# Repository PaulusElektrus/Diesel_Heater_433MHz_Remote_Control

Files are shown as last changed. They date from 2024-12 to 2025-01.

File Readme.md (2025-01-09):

# Diesel Heater 433 MHz Remote Control

This project is based on [ChilliChump`s Project](https://github.com/ChilliChump/Diesel-Heater-433mhz-Remote-Control). 

Its goal is to control a diesel heater to be a frost guard.

The states are as follows:

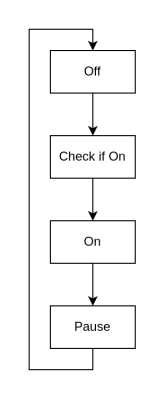
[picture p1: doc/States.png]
States


It is done with an Arduino, DHT22 (temperature sensor) and a 433MHz Transmitter.
We sniff and use the protocoll of the original remote control of the heater.

I use the very nice [Arduino Extension for VSCode](https://github.com/microsoft/vscode-arduino), sadly it is deprecated...

## Projectplan / To-do:

- [X] Basic 433MHz Send & Receive Test
- [X] Sniff Remote Control Codes
- [X] DHT22 integration & test
- [X] Programming
- [X] Design Circuit Board 
- [X] Build Circuit Board
- [X] Final Tests
- [X] Integration

## Basic 433Mhz Send & Receive Test

You can install the [rc-switch library](https://docs.arduino.cc/libraries/rc-switch/) in the library manager of the [Arduino IDE](https://www.arduino.cc/en/software). 

Then the ReceiveDemo_Advanced and the SendDemo can be found under "Examples" in the IDE. Just load it on two separate Microcontrollers and open the serial monitor on the receiving one with baudrate 9600. You should now see the received data which was sent from the transmitting Microcontroller.

## Sniffed Remote Control Codes

I used [the receive demo advanced example script](https://github.com/sui77/rc-switch/tree/master/examples/ReceiveDemo_Advanced) to sniff the remote control codes:

### Chinese Diesel Heater Protocol

#### On:
Decimal: 2794262960 (32Bit) 

Binary: 10100110100011010001000110110000 

Tri-State: not applicable 

PulseLength: 257 microseconds 

Protocol: 1

#### Off:
Decimal: 2794259720 (32Bit) 

Binary: 10100110100011010000010100001000 

Tri-State: not applicable 

PulseLength: 257 microseconds 

Protocol: 1

#### +:
Decimal: 2794260720 (32Bit) 

Binary: 10100110100011010000100011110000 

Tri-State: not applicable 

PulseLength: 257 microseconds 

Protocol: 1

#### -:
Decimal: 2794259080 (32Bit) 

Binary: 10100110100011010000001010001000 

Tri-State: not applicable 

PulseLength: 256 microseconds 

Protocol: 1

## DHT22 Test

The DHT22 can be tested with the [Unified Sensor Example](https://github.com/adafruit/DHT-sensor-library/tree/master/examples/DHT_Unified_Sensor). 

You can install the [DHT sensor library](https://docs.arduino.cc/libraries/dht-sensor-library/) in the library manager. Then the DHT_Unified_Sensor example can be found under "Examples" in the IDE. Just load in on the Microcontroller and open the serial monitor with baudrate 9600. You should see actual temperature and humidity in the serial monitor.

## Schematic

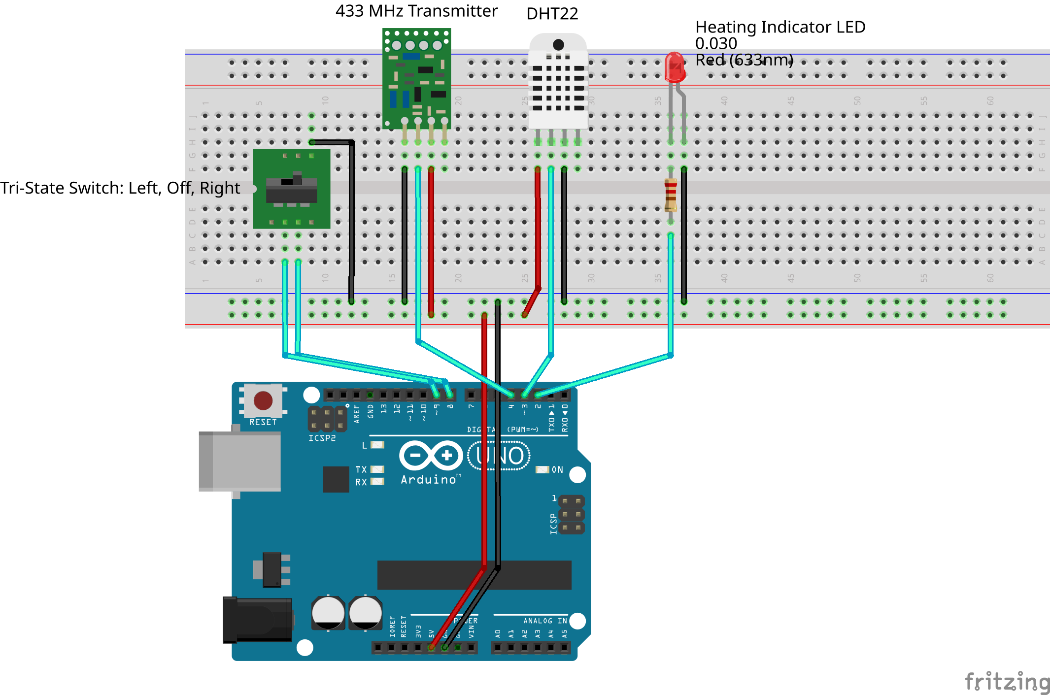
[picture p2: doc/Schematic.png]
Schematic


## Built Project

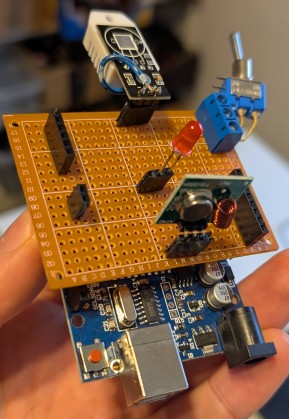
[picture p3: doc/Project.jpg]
Project


## Serial Interface

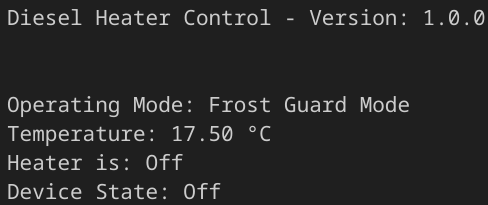
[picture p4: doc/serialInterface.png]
serialInterface


### Admin Mode

Connect to the Microcontroller via serial Inferface:

- Baudrate: 115200
- No line endings!

Then enter "Admin" and send as plain UTF-8 characters.

You can now do the following:

1) Switch On
2) Switch Off
3) Set Debug Temperature
4) Disable Debug
5) Trigger Error
6) Print actual Settings
7) Reset State to Off
8) Trigger serial Report

Every other key ends Admin Mode. You can reenter it by typing "Admin" again.

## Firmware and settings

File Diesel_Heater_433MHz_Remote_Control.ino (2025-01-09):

/* Diesel Heater 433 MHz Remote Control */

#define VERSION             "2.0.1 - PaulusElektrus"             

/* Temperature Sensor Library */
#include <DHT.h>
/* 433 MHz Library */
#include <RCSwitch.h>

/* Pin Assignment */
#define LED_PIN             2
#define DHT_PIN             3
#define TRANSMITTER_PIN     4
#define SWITCH_FROST_GUARD  8
#define SWITCH_AT_HOME      9

/* User Settings */
#define FROST_ON_TEMP               3.0     /* °C */
#define FROST_OFF_TEMP              10.0    /* °C */
#define FROST_PAUSE_TIME            30      /* Minutes */
#define FROST_SWITCH_ON_TIME        10      /* Minutes */
#define FROST_SWITCH_ON_DELTA_T     3.0     /* °C */
#define FROST_MAX_ON_TIME           30      /* Minutes */
#define FROST_RETRY_COUNT           1       /* times */
#define FROST_TIMES_MINUS_KNOB      5       /* times */

#define HOME_ON_TEMP                15.0    /* °C */
#define HOME_OFF_TEMP               25.0    /* °C */
#define HOME_PAUSE_TIME             30      /* Minutes */
#define HOME_SWITCH_ON_TIME         10      /* Minutes */
#define HOME_SWITCH_ON_DELTA_T      3.0     /* °C */
#define HOME_MAX_ON_TIME            30      /* Minutes */
#define HOME_RETRY_COUNT            0       /* times */
#define HOME_TIMES_MINUS_KNOB       5       /* times */

/* Conversion factor from msec to sec */
#define MIN_TO_MSEC                 60000
/* Interval to send serial report */
#define REPORT_TIME                 5000    /* msec */
/* Check temperature interval */
#define TEMP_CHECK_TIME             1000    /* msec */

/* Remote Codes */
#define REMOTE_ON           "10100110100011010001000110110000"
#define REMOTE_OFF          "10100110100011010000010100001000"
#define REMOTE_PLUS         "10100110100011010000100011110000"
#define REMOTE_MINUS        "10100110100011010000001010001000"
#define REMOTE_PULSLENGTH   257

/* States */
enum operatingModes
{
    OFF_MODE,
    FROST_GUARD_MODE,
    AT_HOME_MODE
};

enum heaterStates
{
    OFF, 
    ON,
    PAUSE,
    NO_OPERATION,
    ERROR_STATE,
    SWITCH_ON_PROCESS,
};

const char* heaterStatesStrings[6] = 
{
    "Off",
    "On",
    "Pause",
    "No Operation",
    "Error",
    "Switch On Process"
};

struct settings
{
    float           onTemp;
    float           offTemp;
    unsigned long   minTimeDelay;
    unsigned long   switchOnTime;
    float           switchOnDeltaT;
    unsigned long   maxOnTime;
    unsigned int    retryCount;
    unsigned int    timesMinusKnob;
};

/* Global Variables */
operatingModes  mode            = OFF_MODE;
heaterStates    state           = OFF;
bool            heaterOn        = false;
bool            debugMode       = false;   
float           temp            = NAN;
String          serialInput     = "";
String          errorString     = "No Errors";
settings        frostGuardSettings;
settings        atHomeSettings;
settings        actualSettings;

/* Init Devices*/
DHT         dht(DHT_PIN, DHT22);
RCSwitch    transmitter = RCSwitch();

void setup()
{
    Serial.begin(115200);
    Serial.print("\n\nDiesel Heater Control - Version: ");
    Serial.print(VERSION);
    Serial.println("\n");

    pinMode(LED_PIN, OUTPUT);
    pinMode(LED_BUILTIN, OUTPUT);
    pinMode(SWITCH_FROST_GUARD, INPUT_PULLUP);
    pinMode(SWITCH_AT_HOME, INPUT_PULLUP);

    dht.begin();

    transmitter.enableTransmit(TRANSMITTER_PIN);
    transmitter.setPulseLength(REMOTE_PULSLENGTH);

    frostGuardSettings.onTemp           = FROST_ON_TEMP;
    frostGuardSettings.offTemp          = FROST_OFF_TEMP;
    frostGuardSettings.minTimeDelay     = FROST_PAUSE_TIME * MIN_TO_MSEC;
    frostGuardSettings.switchOnTime     = FROST_SWITCH_ON_TIME * MIN_TO_MSEC;
    frostGuardSettings.switchOnDeltaT   = FROST_SWITCH_ON_DELTA_T;
    frostGuardSettings.maxOnTime        = FROST_MAX_ON_TIME * MIN_TO_MSEC;
    frostGuardSettings.retryCount       = FROST_RETRY_COUNT;
    frostGuardSettings.timesMinusKnob   = FROST_TIMES_MINUS_KNOB;

    atHomeSettings.onTemp               = HOME_ON_TEMP;
    atHomeSettings.offTemp              = HOME_OFF_TEMP;
    atHomeSettings.minTimeDelay         = HOME_PAUSE_TIME * MIN_TO_MSEC;
    atHomeSettings.switchOnTime         = HOME_SWITCH_ON_TIME * MIN_TO_MSEC;
    atHomeSettings.switchOnDeltaT       = HOME_SWITCH_ON_DELTA_T;
    atHomeSettings.maxOnTime            = HOME_MAX_ON_TIME * MIN_TO_MSEC;
    atHomeSettings.retryCount           = HOME_RETRY_COUNT;
    atHomeSettings.timesMinusKnob       = HOME_TIMES_MINUS_KNOB;

    checkOperatingMode();
}

void loop()
{
    checkAdminMode();
    checkOperatingMode();
    checkTemperature();
    setHeater();
    serialReport();
}

void checkAdminMode()
{
    if (Serial.available() > 0)
    {
        char received = Serial.read();

        if (received == 'n')
        {
            adminMode(serialInput);
            serialInput = "";
        } 
        else 
        {
        serialInput += received;
        }

        if (serialInput.length() >= 5)
        {
            serialInput = "";
        }
    }
}

void adminMode(String userInput)
{
    bool adminModeOn = 1;

    userInput.trim();
    if (!userInput.equals("Admi") )
    {
        return;
    }

    Serial.println("\n### Admin Mode ###");
    printAdminMenu();

    while (adminModeOn) 
    {
        if (Serial.available() > 0)
        {
            char received = Serial.read();

            int receivedInt = received - '0';

            switch (receivedInt)
            {
            case 1:
                switchOn();
                Serial.println("Switched manually On");
                break;
            case 2:
                switchOff();
                Serial.println("Switched manually Off");
                break;
            case 3:
                setDebugTemperature();
                break;
            case 4:
                debugMode = false;
                Serial.println("Disabled Debug Mode");
                break;
            case 5:
                error("Test Error");
                Serial.println("Triggered Test Error");
                break;
            case 6:
                printSettings();
                break;
            case 7:
                state = OFF;
                Serial.println("Reset state to Off");
                break;
            case 8:
                serialReport();
                Serial.println("Triggered serial Report function");
                break;
            default:
                adminModeOn = 0;
                Serial.println("\n### Closed Admin Mode ###\n");
                break;
            }
            printAdminMenu();
        }
    }
}

void printAdminMenu()
{
    Serial.println("\n1) Switch On\n2) Switch Off\n3) Set Debug Temperature\n4) Disable Debug\n5) Trigger Error\n6) Print actual Settings\n7) Reset State to Off\n8) Trigger serial Report\n\nEvery other key ends Admin Mode.");
}

void setDebugTemperature()
{
    char buffer[4];
    float debugTemp;

    Serial.println("Set temperature for debug tests in format: (+/-XX)");

    while (Serial.available() < 3)
    {
        /* Wait */
    }
    for (int i = 0; i < 3; i++)
    {
        buffer[i] = Serial.read();
    }

    buffer[3] = '\0';

    if ((buffer[0] == '-' || buffer[0] == '+') && isdigit(buffer[1]) && isdigit(buffer[2]))
    {
        debugTemp = atof(buffer);
        Serial.print("Debug Temperature set to: ");
        Serial.println(debugTemp);
        temp = debugTemp;
        debugMode = true;
        return;
    }

    Serial.println("Please try again...");
}

void printSettings()
{
    Serial.println("\n### Settings ###\n");
    Serial.print("- On Temp: ");
    Serial.println(actualSettings.onTemp);
    Serial.print("- Off Temp: ");
    Serial.println(actualSettings.offTemp);
    Serial.print("- Min Time Delay: ");
    Serial.println(actualSettings.minTimeDelay);
    Serial.print("- Switch On Time: ");
    Serial.println(actualSettings.switchOnTime);
    Serial.print("- Switch On Delta T: ");
    Serial.println(actualSettings.switchOnDeltaT);
    Serial.print("- Max On Time: ");
    Serial.println(actualSettings.maxOnTime);
    Serial.print("- Retry Count: ");
    Serial.println(actualSettings.retryCount);
    Serial.print("- Times Minus Knob: ");
    Serial.println(actualSettings.timesMinusKnob);
}

void checkOperatingMode()
{
    /* No operating mode changes during Switch On */
    if (state < SWITCH_ON_PROCESS)
    {
        if (!digitalRead(SWITCH_FROST_GUARD))
        {
            mode = FROST_GUARD_MODE;
            actualSettings = frostGuardSettings;
        }
        else if (!digitalRead(SWITCH_AT_HOME))
        {
            mode = AT_HOME_MODE;
            actualSettings = atHomeSettings;
        }
    }
}

void checkTemperature()
{
    static unsigned long lastReport = millis();

    if (millis() - lastReport >= TEMP_CHECK_TIME)
    {
        if (false == debugMode)
        {
            temp = dht.readTemperature();
            if (isnan(temp))
            {
                error("No temperature sensor data available");
            }
        }
    }
}

void setHeater()
{
    static unsigned long    lastTime        = millis();
    static float            lastTemp        = temp;
    static unsigned int     retryCountOn    = 0;
    static unsigned int     retryCountOff   = 0;

    switch (state)
    {
    case OFF:
        retryCountOff = 0;
        if (temp <= actualSettings.onTemp)
        {
            switchOn();
            lastTemp = temp;
            state = SWITCH_ON_PROCESS;
        }
        lastTime = millis();
        break;

    case SWITCH_ON_PROCESS:
        if (temp >= lastTemp + actualSettings.switchOnDeltaT)
        {
            state = ON;
        }
        else if (millis() - lastTime >= actualSettings.switchOnTime)
        {
            if (actualSettings.retryCount >= retryCountOn)
            {
                error("Heater has not switched On");
            }
            else
            {
                state = OFF;
                retryCountOn++;
            }
        }
        break;

    case ON:
        retryCountOn = 0;
        if ((temp >= actualSettings.offTemp) || (millis() - lastTime >= actualSettings.maxOnTime))
        {
            switchOff();
            state = PAUSE;
            lastTime = millis();
        }
        break;

    case PAUSE:
        if (millis() - lastTime >= actualSettings.minTimeDelay)
        {
            state = OFF;
        }
        break;

    case NO_OPERATION:
        /* fall through */
    case ERROR_STATE:
        /* fall through */
    default:
        if (heaterOn)
        {
            switchOff();
        }
        break;
    }
}

void switchOn()
{
    digitalWrite(LED_PIN, 1);
    for (int i = 0; i < 1; i++)
    {
        transmitter.send(REMOTE_ON);
        delay(100);
    }
    minimalPower();
    heaterOn = HIGH;
    
}

void switchOff()
{
    digitalWrite(LED_PIN, 0);
    for (int i = 0; i < 5; i++)
    {
        transmitter.send(REMOTE_OFF);
        delay(100);
    }
    heaterOn = LOW;
}

void fullPower()
{
    for (int i = 0; i < 15; i++)
    {
        transmitter.send(REMOTE_PLUS);
        delay(100);
    }
}

void minimalPower()
{
    for (int i = 0; i < actualSettings.timesMinusKnob; i++)
    {
        transmitter.send(REMOTE_MINUS);
        delay(100);
    }
}

void serialReport()
{
    static unsigned long lastReport = millis();

    if (millis() - lastReport >= REPORT_TIME)
    {
        Serial.print("\nOperating Mode: ");
        if (FROST_GUARD_MODE == mode)
        {
            Serial.println("Frost Guard Mode");
        }
        else if (AT_HOME_MODE == mode)
        {
            Serial.println("At Home Mode");
        }
        else
        {
            Serial.println("Off Mode");
        }
        
        Serial.print("Temperature: ");
        Serial.print(temp);
        Serial.println(" °C");

        Serial.print("Heater is: ");
        if (true == heaterOn)
        {
            Serial.println("On");
        }
        else
        {
            Serial.println("Off");
        }

        Serial.print("Device State: ");
        Serial.println(heaterStatesStrings[state]);

        if (ERROR_STATE == state)
        {
            Serial.print("Error Occured: ");
            Serial.println(errorString);
        }

        if (true == debugMode)
        {
            Serial.println("\n### Debug Mode enabled ###");
        }

        lastReport = millis();
    }
}

void error(String newErrorString)
{
    state = ERROR_STATE;
    errorString = newErrorString;
    digitalWrite(LED_BUILTIN, HIGH);
}

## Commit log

2024-12-29 Add Schematic
    [Schematic.fzz]
2025-01-04 Added image of project
    [Schematic.fzz]
2025-01-09 Updated printSettings() function with minus knob setting
2025-01-09 Fixed bug if temp is way below onTemp when switching device on. So I added a lastTemp variable.
    [Diesel_Heater_433MHz_Remote_Control.ino]
